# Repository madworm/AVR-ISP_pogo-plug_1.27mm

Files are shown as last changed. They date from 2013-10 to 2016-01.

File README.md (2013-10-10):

AVR-ISP_pogo-plug_1.27mm
========================

LAYOUT FILES: AVR-ISP adapter: 6pin (2.54mm) --> 6pin pogo-pins (1.27mm). 

When your boards get smaller and smaller and it gets harder and harder
to find a spot for the programming connector.

Pogo-pin type: "P50 - E2", 0.68mm body diameter, 0.9mm head diameter.

PCB thickness: 0.6mm !

---

Before having PC-boards made, please make sure you know about your manufacturer's peculiarities!
Especially drill-sizes and their tolerances may vary too much and give you trouble.

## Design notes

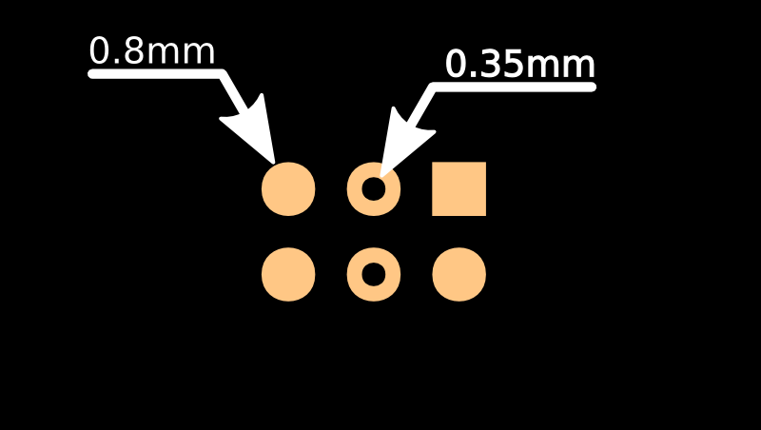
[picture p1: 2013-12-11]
Docs/footprint.png

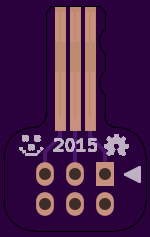
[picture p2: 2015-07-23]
gerber_files/PNGs/AVR-ISP-pogo-plug-1.27mm__front_purple.png

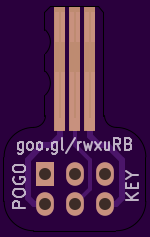
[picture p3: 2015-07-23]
gerber_files/PNGs/AVR-ISP-pogo-plug-1.27mm__back_purple.png

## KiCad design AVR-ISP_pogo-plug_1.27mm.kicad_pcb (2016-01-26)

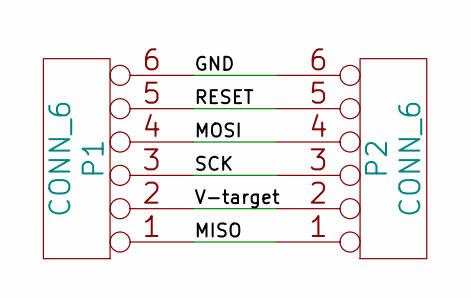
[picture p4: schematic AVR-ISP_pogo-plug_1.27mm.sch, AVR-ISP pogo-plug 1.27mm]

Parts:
P1, P2: CONN_6

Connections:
/GND: P1.6, P2.6
/MISO: P1.1, P2.1
/MOSI: P1.4, P2.4
/RESET: P1.5, P2.5
/SCK: P1.3, P2.3
/V-target: P1.2, P2.2

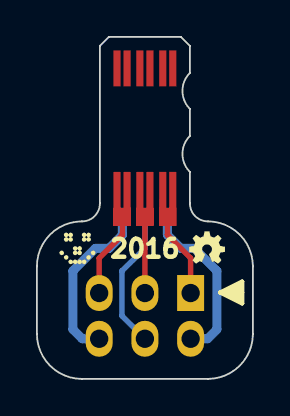
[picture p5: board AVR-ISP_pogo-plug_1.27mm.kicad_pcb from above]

Board: 2 copper layers, 12.0 x 19.0 mm, 4 parts (0 on the bottom side), 6 nets.

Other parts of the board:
G1: LED_smile_silkscreen_2mm
G2: OSHW-logo_silkscreen_2mm

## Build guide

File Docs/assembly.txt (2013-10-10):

The idea is to line up the pogo pins in the small grooves formed by the finger shaped pads.
Once lined up and depth-adjusted, tack them down and finalize the solder job.

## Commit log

2013-05-25 Initial commit.
    [AVR-ISP_pogo-plug_1.27mm-B_Cu.gbl, AVR-ISP_pogo-plug_1.27mm-B_Mask.gbs, AVR-ISP_pogo-plug_1.27mm-B_SilkS.gbo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]
2013-06-09 Added 2 break-away sub-boards supposed to act as pogo-pin stabilizers.
    [AVR-ISP_pogo-plug_1.27mm.kicad_pcb]
2013-06-09 Reduced to just one stabilizer board.
    [AVR-ISP_pogo-plug_1.27mm.kicad_pcb]
2013-06-10 Board outline tweaks.
    [AVR-ISP_pogo-plug_1.27mm.kicad_pcb]
2013-06-13 Rounded corners.
    [AVR-ISP_pogo-plug_1.27mm-B_Cu.gbl, AVR-ISP_pogo-plug_1.27mm-B_Mask.gbs, AVR-ISP_pogo-plug_1.27mm-B_SilkS.gbo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]
2013-07-05 Got the boards: marginal annular ring --> increased pad-size to 1.65mm.
    [AVR-ISP_pogo-plug_1.27mm.kicad_pcb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]
2013-09-02 Changed some traces. Don't connect to pads next to drills.
    [AVR-ISP_pogo-plug_1.27mm.kicad_pcb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]
2013-09-04 Added sub-boards to triple board thickness for better pogo-pin alignment.
    [AVR-ISP_pogo-plug_1.27mm-B_Cu.gbl, AVR-ISP_pogo-plug_1.27mm-B_Mask.gbs, AVR-ISP_pogo-plug_1.27mm-B_SilkS.gbo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]
2013-09-29 Drill-size issues again...
    [AVR-ISP_pogo-plug_1.27mm-B_Cu.gbl, AVR-ISP_pogo-plug_1.27mm-B_Mask.gbs, AVR-ISP_pogo-plug_1.27mm-B_SilkS.gbo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]
2013-09-29 Stacking PCBs doesn't work. Too imprecise. THICK PCB could solve it.
    [AVR-ISP_pogo-plug_1.27mm-B_Cu.gbl, AVR-ISP_pogo-plug_1.27mm-B_Mask.gbs, AVR-ISP_pogo-plug_1.27mm-B_SilkS.gbo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]
2013-09-29 Revert "Stacking PCBs doesn't work. Too imprecise. THICK PCB could solve it."
    This reverts commit 490f224e26ced886a5e1a4095987a5f097893897.
    [AVR-ISP_pogo-plug_1.27mm-B_Cu.gbl, AVR-ISP_pogo-plug_1.27mm-B_Mask.gbs, AVR-ISP_pogo-plug_1.27mm-B_SilkS.gbo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]
2013-09-29 Revert "Drill-size issues again..."
    This reverts commit 78704ad755869ccbc9e371843dd45850562db76e.
    [AVR-ISP_pogo-plug_1.27mm-B_Cu.gbl, AVR-ISP_pogo-plug_1.27mm-B_Mask.gbs, AVR-ISP_pogo-plug_1.27mm-B_SilkS.gbo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]
2013-09-29 Revert "Added sub-boards to triple board thickness for better pogo-pin alignment."
    This reverts commit 808a31bfee8c9cebc64c52d68362d3861d50fe81.
    [AVR-ISP_pogo-plug_1.27mm-B_Cu.gbl, AVR-ISP_pogo-plug_1.27mm-B_Mask.gbs, AVR-ISP_pogo-plug_1.27mm-B_SilkS.gbo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]
2013-10-01 New idea how to assemble the pogo-pins.
    * one sub-board is an 'align tool' with small drills,
    so the heads can register with them.
    * the other's holes are large enough for the pins'
    shafts. This should stabilize the pins sideways.
    [AVR-ISP_pogo-plug_1.27mm-B_Cu.gbl, AVR-ISP_pogo-plug_1.27mm-B_Mask.gbs, AVR-ISP_pogo-plug_1.27mm-B_SilkS.gbo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]
2013-10-10 Experimenting with yet another scheme (0.6mm PCBs).
    [AVR-ISP_pogo-plug_1.27mm-B_Cu.gbl, AVR-ISP_pogo-plug_1.27mm-B_Mask.gbs, AVR-ISP_pogo-plug_1.27mm-B_SilkS.gbo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]
2013-10-10 Changed the board-outline a bit.
    [AVR-ISP_pogo-plug_1.27mm.kicad_pcb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]
2013-10-10 Made it look more like a key.
    [AVR-ISP_pogo-plug_1.27mm.kicad_pcb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]
2013-10-10 Using 'Solder mask win width' polygonizes round pad outlines :-(
    [AVR-ISP_pogo-plug_1.27mm.kicad_pcb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]
2013-10-17 Removed solder mask at board edge <--> pogo-pin flat on pads.
    [AVR-ISP_pogo-plug_1.27mm.kicad_pcb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]
2013-12-11 Added suggested footprint info to Docs folder.
2013-12-19 Tweaked split pads footprint for hopefully better axial alignment.
    [AVR-ISP_pogo-plug_1.27mm.kicad_pcb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]
2013-12-19 Board outline tweaks. Looks more like a key + better pin-1 ident.
    [AVR-ISP_pogo-plug_1.27mm.kicad_pcb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]
2014-09-18 Removed "key-hole" to allow for 90° 3x2 header.
    [AVR-ISP_pogo-plug_1.27mm-B_Cu.gbl, AVR-ISP_pogo-plug_1.27mm-B_Mask.gbs, AVR-ISP_pogo-plug_1.27mm-B_SilkS.gbo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]
2015-07-23 Tweakes pogo footprint. Space for dot of glue.
    [AVR-ISP_pogo-plug_1.27mm-B_Cu.gbl, AVR-ISP_pogo-plug_1.27mm-B_Mask.gbs, AVR-ISP_pogo-plug_1.27mm-B_SilkS.gbo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]
2015-07-23 Fixed pad offset.
    [AVR-ISP_pogo-plug_1.27mm.kicad_pcb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]
2016-01-26 Shorter pogo-pin split-pad footprints. Less chance to mess things up.
    [AVR-ISP_pogo-plug_1.27mm.kicad_pcb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]
2016-02-02 Added 4 drill hits to allow wiring down pogo-pins for assembly.
    [AVR-ISP_pogo-plug_1.27mm.kicad_pcb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]
2016-08-19 Revert "Added 4 drill hits to allow wiring down pogo-pins for assembly."
    This reverts commit c23f7a8ddcae17a2ea3c2f7512045aeab9fe0c27.
    Reason: mechanical stability severely compromised.
    [AVR-ISP_pogo-plug_1.27mm.kicad_pcb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]
2016-08-19 Renamed gerber files to match KiCad's new standard names.
    [AVR-ISP_pogo-plug_1.27mm-B.Cu.gbl, AVR-ISP_pogo-plug_1.27mm-B.Mask.gbs, AVR-ISP_pogo-plug_1.27mm-B.SilkS.gbo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]
